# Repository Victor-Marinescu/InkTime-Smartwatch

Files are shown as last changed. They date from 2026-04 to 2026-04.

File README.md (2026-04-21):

# InkTime Smartwatch Project

**InkTime** este un smartwatch conceptual bazat pe microcontrolerul **nRF52840**, proiectat pentru autonomie ridicată prin utilizarea unui ecran E-Paper și optimizarea consumului de energie.

---

## 1. Diagramă Bloc
Sistemul este organizat în jurul MCU-ului nRF52840, care gestionează comunicația cu senzorii via I2C și controlul ecranului via SPI.

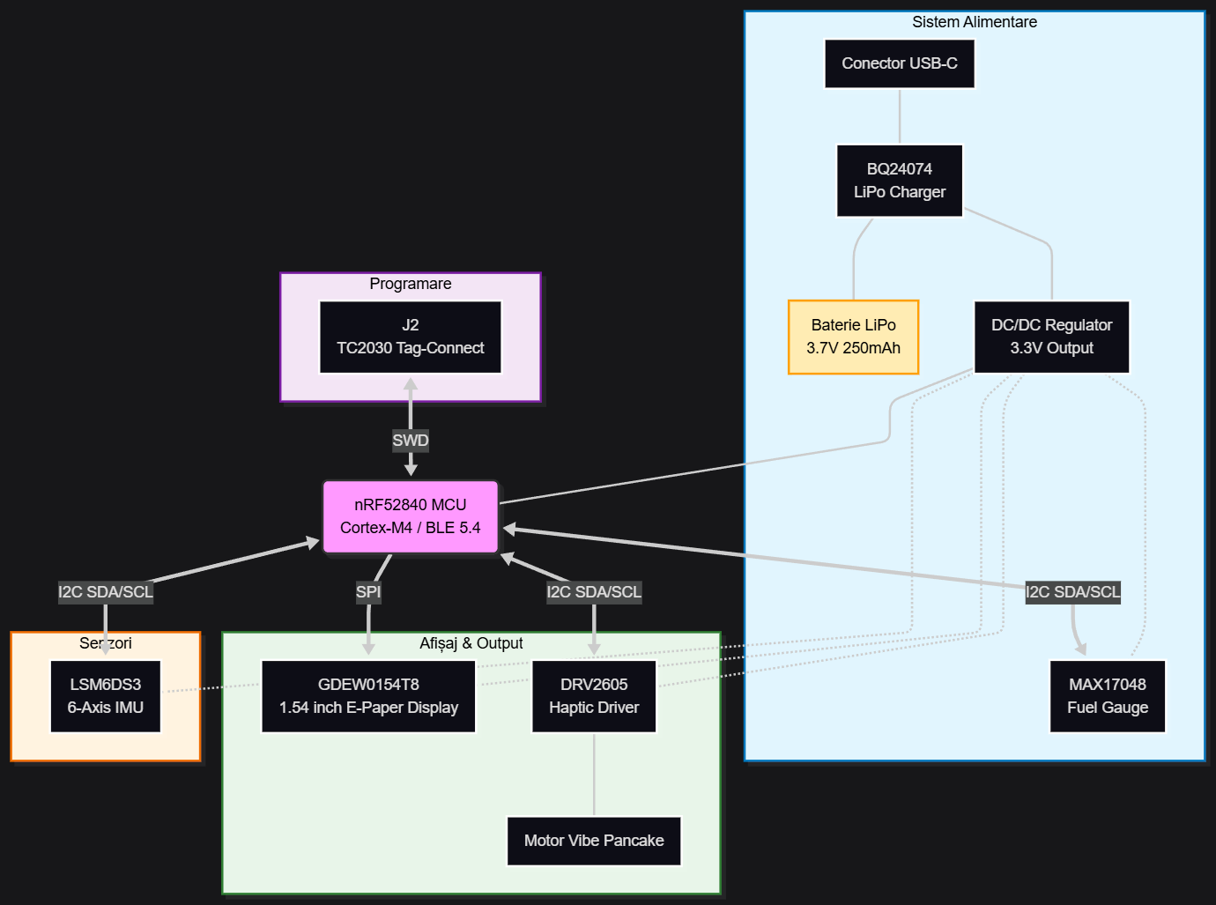
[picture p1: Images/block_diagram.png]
Diagrama Bloc a Sistemului


## 2. Bill Of Materials (BOM)

| Componentă | Descriere | Datasheet |
| :--- | :--- | :--- |
| **nRF52840** | MCU Bluetooth 5.4, ARM Cortex-M4 | [Link](https://jlcpcb.com/partdetail/NordicSemicon-NRF52840_QFAA_FR7/C3606653) |
| **5034802400** | 1.54" E-Paper Display (SPI) | [Link](https://jlcpcb.com/partdetail/MOLEX-5034802400/C122434) |
| **MAX17048** | Fuel Gauge (Monitorizare Baterie) | [Link](https://jlcpcb.com/partdetail/2777647-MAX17048GT10/C2682616) |
| **DRV2605** | Haptic Driver (LRA/ERM) | [Link](https://jlcpcb.com/partdetail/TexasInstruments-DRV2605YZFR/C81079) |
| **LSM6DS3** | IMU (Accelerometru & Giroscop) | [Link](https://jlcpcb.com/partdetail/STMicroelectronics-LSM6DS3TR/C95230) |
| **BQ25180** | IC Management Încărcare Baterie | [Link](https://jlcpcb.com/partdetail/TexasInstruments-BQ25180YBGR/C3682423) |
| **RT6160** | Regulator Buck-Boost 3.3V 2.4A | [Link](https://jlcpcb.com/partdetail/RichtekTech-RT6160AWSC/C7065276) |

---

## 3. Descriere Funcționalitate Hardware

### Module și Senzori
* **Microcontroler (MCU):** nRF52840 (AQFN-73) coordonează procesele BLE și perifericele. Decuplare locală via C14 (4.7 µF), C7/C8/C12 (100 nF).
* **Afișaj E-Paper:** Conectat prin **SPI**. Include pompă de tensiune cu L5 (68 µH) și switch de alimentare Q1/Q3 pentru consum zero în sleep.
* **Haptic Feedback:** Driver DRV2605 (I2C: 0x5A) capabil să ruleze peste 123 de efecte tactile din librăria ROM.
* **Power Management:** * **BQ25180:** Încărcător inteligent (I2C: 0x6A) cu Power Path.
    * **MAX17048:** Monitorizare SOC (I2C: 0x36) via algoritm ModelGauge.
    * **RT6160:** Buck-Boost pentru prag stabil de 3.3V chiar și la descărcarea bateriei sub 3.3V.

---

## 4. Configurație Detaliată Pini (nRF52840)

Am extras configurația completă a pinilor conform mapării hardware finale:

| Pin MCU | AQFN-73 | Funcție | Destinație Hardware | Note Tehnice |
| :--- | :--- | :--- | :--- | :--- |
| **P0.02** | A12 | **SCK** | J1 pin 14 (EPD) | Clock SPI Afișaj |
| **P0.03** | B13 | **MOSI** | J1 pin 15 (EPD) | Date SPI Afișaj |
| **P0.05** | A14 | **CS** | J1 pin 13 (EPD) | Chip Select (Activ LOW) |
| **P0.06** | B15 | **SDA** | I2C Bus Shared | Date senzori (R18 pull-up 3.3k) |
| **P0.07** | A16 | **SCL** | I2C Bus Shared | Clock senzori (R17 pull-up 3.3k) |
| **P0.15** | B19 | **EPD_DC** | J1 pin 11 (EPD) | Data/Command Select |
| **P0.16** | A20 | **EPD_RST**| J1 pin 10 (EPD) | Reset Hardware Afișaj |
| **P0.17** | B21 | **BUSY** | J1 pin 9 (EPD) | Monitorizare stare afișaj |
| **P1.01** | AD22 | **EPD_EN** | Q1 PMOS Gate | Control Power-Cut ecran |
| **P0.13** | AD16 | **SW_UP** | Buton UP | Intrare Digitală (R14 pull-up 10k) |
| **P0.12** | AC17 | **SW_ENT**| Buton ENTER | Intrare Digitală (R15 pull-up 10k) |
| **P0.11** | AD18 | **SW_DN** | Buton DOWN | Intrare Digitală (R16 pull-up 10k) |
| **ANT** | H23 | **RF** | Antenă Ceratent | Adaptare 50 Ω (L1, C3, C4) |
| **SWDIO** | AC24 | **DIO** | J2 pin 2 (Debug) | Programare Serial Wire Data |
| **SWDCLK**| AA24 | **CLK** | J2 pin 4 (Debug) | Programare Serial Wire Clock |

---

## 5. Strategie Design și Review

### Detalii PCB (4 Layere)
* **Lățime Trasee Putere:** 0.3 mm pentru rețelele `VBUS`, `VBAT`, `VREG` și `3V3`.
* **Trasee Date:** 0.15 mm pentru I2C, SPI și semnalele de control.
* **Stackup:**
    * **Layer 1 (Top):** Componente, RF (Antenă) și semnale critice.
    * **Layer 2:** Plan dedicat de alimentare (3.3V / VREG).
    * **Layer 63 (Mid):** Trasee secundare de date.
    * **Layer 64 (Bottom):** Plan de masă (GND) continuu sub zona RF.

### Estimare Consum Energetic
* **MCU (Sleep + RTC + BLE Adv 1Hz):** ~200 µA
* **BMA423 (Pedometru Low-Power):** ~130 µA
* **MAX17048 (Activ):** ~23 µA
* **RT6160 Quiescent:** ~30 µA
* **Total Mediu:** **~390 µA**
* **Autonomie:** ~10 zile (baterie 100mAh) / ~25 zile (baterie 250mAh).

---

## 6. Erori DRC Ignorate 

### Overlap (6 erori)
* **Localizare:** Cele 3 butoane laterale (UP, ENT, DN).
* **Justificare:** Suprapunere asumată între pinii mecanici și via-urile de semnal.

### Drill size (11 erori)
* **Localizare:** Pinii înconjurați de alți pini, fara acces la exterior.
* **Justificare:** S-a folosit câte un via pentru a face conexiunea între pini fără a avea erori de tip Copper Clearance.

### Board Outline Clearance (4 erori)
* **Localizare:** Conector USB-C (J4).
* **Justificare:** Cupru extins până în Dimension layer pentru a asigura fixarea structurală a mufei la marginea carcasei.

---
Licensed under the [Apache 2.0](LICENSE).

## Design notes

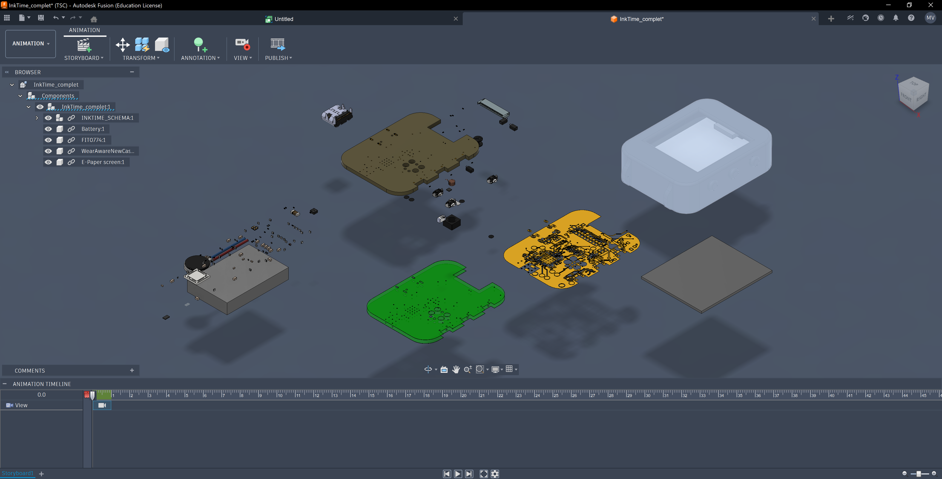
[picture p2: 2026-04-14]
Mechanical/InkTime_explodat.png

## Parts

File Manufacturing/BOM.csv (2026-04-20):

Qty | Value | Device | Package | Parts | Description | ARROW_PART_NUMBER | ARROW_PRICE-STOCK | AVAILABILITY | CHECK_PRICES | COPYRIGHT | DESCRIPTION | DIGI-KEY_PART_NUMBER_1 | DIGI-KEY_PART_NUMBER_2 | DIGI-KEY_PART_NUMBER_3 | HEIGHT | JLCPCB | MANUFACTURER_NAME | MANUFACTURER_PART_NUMBER | MF | MFR_NAME | MOUSER_PART_NUMBER | MOUSER_PRICE-STOCK | MP | PACKAGE | POPULARITY | PRICE | PROD_ID | PURCHASE-URL | SNAPEDA_LINK | TP_SIGNAL_NAME | VALUE
3 | 0 | CPF0201D7K68C1_CPF0201D7K68C1 | CPF0201D7K68C1_0201 | R1, R2, R4 | 7.68k 0201 Thin Film Surface Mount Fixed Resistor +/-0.5% 0.031W CPF0201D7K68C1
1 | 0 | ESP32_C6_LIBRARY_7_JUMPER_SJ | ESP32_C6_LIBRARY_7_JUMPER_SJ | SJ1 | SMD solder JUMPER |  |  |  |  |  |  |  |  |  |  |  |  |  |  |  |  |  |  |  | 3
1 | 0.1uF | GRM011R60J152KE01L_1_GRM011R60J152KE01L | GRM011R60J152KE01L_1_0201 | C42 | Check availability
3 | 0.1uF | NORDIC_NRF_3_CAPACITOR_0201_L | NORDIC_NRF_3_RESC0201_L | C23, C27, C34 | Generic chip capacitor
1 | 0.1uF/50V | NORDIC_NRF_3_CAPACITOR_0201_L | NORDIC_NRF_3_RESC0201_L | EPD_C5 | Generic chip capacitor
1 | 0.47 | CPF0201D7K68C1_CPF0201D7K68C1 | CPF0201D7K68C1_0201 | R1_EP_DR | 7.68k 0201 Thin Film Surface Mount Fixed Resistor +/-0.5% 0.031W CPF0201D7K68C1
5 | 100nF | NORDIC_NRF_3_CAPACITOR_0201_L | NORDIC_NRF_3_RESC0201_L | C5, C7, C8, C12, C19 | Generic chip capacitor
1 | 100pF | NORDIC_NRF_3_CAPACITOR_0201_L | NORDIC_NRF_3_RESC0201_L | C11 | Generic chip capacitor
6 | 10K | CPF0201D7K68C1_CPF0201D7K68C1 | CPF0201D7K68C1_0201 | R2_EP_DR, R5, R7, R8, R9, R_PWR_EPD | 7.68k 0201 Thin Film Surface Mount Fixed Resistor +/-0.5% 0.031W CPF0201D7K68C1
1 | 10uF | NORDIC_NRF_3_CAPACITOR_0402_L | NORDIC_NRF_3_RESC0402_L | C1-EP-DR | Generic chip capacitor
1 | 10uF | NORDIC_NRF_3_CAPACITOR_0402_N | NORDIC_NRF_3_RESC0402_N | C24 | Generic chip capacitor
1 | 10uF | PERFECT_0402_CAP_0402 | PERFECT_0402_0402 | C39 | 0402 (1005 Metric)
1 | 10uH | NORDIC_NRF_2_INDUCTOR_0201_L | NORDIC_NRF_2_RESC0201_L | L2 | Generic chip inductor
4 | 12pF | NORDIC_NRF_3_CAPACITOR_0201_L | NORDIC_NRF_3_RESC0201_L | C17, C18, XC1, XC2 | Generic chip capacitor
1 | 15nH | NORDIC_NRF_2_INDUCTOR_0201_L | NORDIC_NRF_2_RESC0201_L | L3 | Generic chip inductor
2 | 1pF | NORDIC_NRF_3_CAPACITOR_0201_L | NORDIC_NRF_3_RESC0201_L | C3, C4 | Generic chip capacitor
5 | 1uF | NORDIC_NRF_3_CAPACITOR_0402_L | NORDIC_NRF_3_RESC0402_L | C15, C29, C30, C31, C32 | Generic chip capacitor
2 | 1uF | NORDIC_NRF_3_CAPACITOR_0402_N | NORDIC_NRF_3_RESC0402_N | C37, C38 | Generic chip capacitor
9 | 1uF/50V | NORDIC_NRF_3_CAPACITOR_0402_L | NORDIC_NRF_3_RESC0402_L | EPD_C1, EPD_C2, EPD_C6, EPD_C7, EPD_C8, EPD_C9, EPD_C10, EPD_C11, EPD_C12 | Generic chip capacitor
1 | 2.2 | CPF0201D7K68C1_CPF0201D7K68C1 | CPF0201D7K68C1_0201 | R_TYPE_SEL | 7.68k 0201 Thin Film Surface Mount Fixed Resistor +/-0.5% 0.031W CPF0201D7K68C1
3 | 2025-10-22_07-23-44_LIBRARY_EVP-AKE31ASW_EVP-AKE31A_PAN | 2025-10-22_07-23-44_LIBRARY_EVP-AKE31ASW_EVP-AKE31A_PAN | 2025-10-22_07-23-44_LIBRARY_SW_EVP-AKE31A_PAN | SW_DN, SW_ENT, SW_UP |  |  |  |  |  | Copyright (C) 2025 Ultra Librarian. All rights reserved. |  | P123437TR-ND | P123437CT-ND | P123437DKR-ND |  |  | Panasonic | EVP-AKE31A
1 | 20V/4.2A/52mO/1.4W | ESP32_C6_LIBRARY_4_ESP32_WROVER_SPARKFUN-DISCRETESEMI_MOSFET_PCH-DMG2305UX-7 | ESP32_C6_LIBRARY_4_ESP32_C6_LIBRARY_4_ESP32_C6_LIBRARY_4_ESP32_C6_LIBRARY_4_ESP32_WROVER_SPARKFUN-DISCRETESEMI_SOT23-3 | DMG2305UX-7 | P-channel MOSFETs |  |  |  |  |  |  |  |  |  |  |  |  |  |  |  |  |  |  |  |  |  | TRAN-14388 |  |  |  | 20V/4.2A/52mO/1.4W
2 | 22uF | NORDIC_NRF_3_CAPACITOR_0402_N | NORDIC_NRF_3_RESC0402_N | C25, C33 | Generic chip capacitor
1 | 2450AT18B100E | 2450AT18B100E_2450AT18B100E | 2450AT18B100E_ANTC3216X140N | ANT1 | Antennas 2.45GHz ANTENNA | 2450AT18B100E | https://www.arrow.com/en/products/2450at18b100e/johanson-dielectrics?utm_currency=USD&region=nac |  |  |  | Antennas 2.45GHz ANTENNA |  |  |  | 1.4mm |  | JOHANSON TECHNOLOGY | 2450AT18B100E |  |  | 609-2450AT18B100E | https://www.mouser.co.uk/ProductDetail/Johanson-Technology/2450AT18B100E?qs=yCnrNFeXz%252Bh5MFsFIXGZGA%3D%3D
1 | 3.9nH | NORDIC_NRF_2_INDUCTOR_0201_L | NORDIC_NRF_2_RESC0201_L | L1 | Generic chip inductor
1 | 32.768kHz | NORDIC_NRF_1_XTAL_32KHZ | NORDIC_NRF_1_XTAL_3215_N | X2
1 | 32MHz | NORDIC_NRF_XTAL_32MHZ | NORDIC_NRF_BT-XTAL_2016_N | X1
2 | 3K3 | CPF0201D7K68C1_CPF0201D7K68C1 | CPF0201D7K68C1_0201 | R17, R18 | 7.68k 0201 Thin Film Surface Mount Fixed Resistor +/-0.5% 0.031W CPF0201D7K68C1
1 | 4.7uF | NORDIC_NRF_3_CAPACITOR_0603_N | NORDIC_NRF_3_RESC0603_N | C43 | Generic chip capacitor
4 | 4.7uF | PERFECT_0402_CAP_0402 | PERFECT_0402_0402 | C6, C14, C20, C21 | 0402 (1005 Metric)
1 | 4.7uF/25V | NORDIC_NRF_3_CAPACITOR_0402_L | NORDIC_NRF_3_RESC0402_L | C2-EP-DR | Generic chip capacitor
1 | 47nF | PERFECT_0402_CAP_0402 | PERFECT_0402_0402 | C16 | 0402 (1005 Metric)
1 | 503480-2400 | 503480-2400_503480-2400 | 503480-2400_5034802400 | J1 | FFC & FPC Connectors 0.5mm FPC RA SMT Dual Contact 24Ckt |  |  |  |  |  | FFC & FPC Connectors 0.5mm FPC RA SMT Dual Contact 24Ckt |  |  |  | 1.87mm |  | Molex | 503480-2400 |  |  | 538-503480-2400 | https://www.mouser.co.uk/ProductDetail/Molex/503480-2400?qs=OAhjpuo3Vu7efIoxFh9AOw%3D%3D
2 | 5K1 | CPF0201D7K68C1_CPF0201D7K68C1 | CPF0201D7K68C1_0201 | R1_USB, R2_USB | 7.68k 0201 Thin Film Surface Mount Fixed Resistor +/-0.5% 0.031W CPF0201D7K68C1
1 | 68uH | ESP32_C6_LIBRARY_2_744043680IND_4828-WE-TPC_WRE | ESP32_C6_LIBRARY_2_IND_4828-WE-TPC_WRE | L5 |  |  |  |  |  | Copyright (C) 2024 Ultra Librarian. All rights reserved. |  |  |  |  |  |  |  | 744043680 |  | Wurth Electronics
1 | 820pF | NORDIC_NRF_3_CAPACITOR_0201_L | NORDIC_NRF_3_RESC0201_L | C9 | Generic chip capacitor
1 | BMA423 | BMA423_BMA423 | BMA423_BMA423 | IC3 | Accelerometers Triaxial low-g 12bit Acceleration Sensor | BMA423 | https://www.arrow.com/en/products/bma423/bosch |  |  |  | Accelerometers Triaxial low-g 12bit Acceleration Sensor |  |  |  | 1mm |  | BOSCH | BMA423 |  |  | 262-BMA423 | https://www.mouser.co.uk/ProductDetail/Bosch-Sensortec/BMA423?qs=HXFqYaX1Q2xC%252BSgeGoX3mg%3D%3D
1 | BQ25180YBGR | BQ25180YBGR_BQ25180YBGR | BQ25180YBGR_BGA8C40P2X4_100X155X50 | IC1 | Charger IC Lithium Ion/Polymer, Lithium Iron Phosphate 8-DSBGA (1.6x1.1) | BQ25180YBGR | https://www.arrow.com/en/products/bq25180ybgr/texas-instruments?utm_currency=USD&region=nac |  |  |  | Charger IC Lithium Ion/Polymer | Lithium Iron Phosphate 8-DSBGA (1.6x1.1) |  |  |  | 0.5mm |  | Texas Instruments | BQ25180YBGR |  |  | 595-BQ25180YBGR | https://www.mouser.co.uk/ProductDetail/Texas-Instruments/BQ25180YBGR?qs=doiCPypUmgEWjAK%252BJAX6Tw%3D%3D
1 | DRV2605YZFR | DRV2605YZFR_DRV2605YZFR | DRV2605YZFR_BGA9C50P3X3_144X144X62 | IC4 | Haptic Driver for ERM/LRA with Built-In Library and Smart Loop Architecture | DRV2605YZFR | https://www.arrow.com/en/products/drv2605yzfr/texas-instruments?region=nac |  |  |  | Haptic Driver for ERM/LRA with Built-In Library and Smart Loop Architecture |  |  |  | 0.625mm |  | Texas Instruments | DRV2605YZFR
1 | FTC252012SR47MBCA | MLP2016SR47MT0S1_FTC252012SR47MBCA | MLP2016SR47MT0S1_INDC2016X100N | L7 | SMD / SMT Inductors (Coils), L=0.47?H, L x W x T : |  |  |  |  |  | SMD / SMT Inductors (Coils) | L=0.47?H | L x W x T : |  |  |  | 1mm | https://jlcpcb.com/partdetail/6763488-FTC252012SR47MBCA/C5832368 | TDK | FTC252012SR47MBCA
12 | HECTOR_WATCH_1_TPTP20R | HECTOR_WATCH_1_TPTP20R | HECTOR_WATCH_1_TP20R | TP_3.3V, TP_3V3, TP_BAT_GND, TP_GND, TP_RESET, TP_SCL, TP_SDA, TP_SWDCLK, TP_SWDIO, TP_SWO, TP_VBAT, TP_VREG | Test pad |  |  |  |  |  |  |  |  |  |  |  |  |  |  |  |  |  |  |  | 2
1 | KH-TYPE-C-16P | KH-TYPE-C-16P_KH-TYPE-C-16P | KH-TYPE-C-16P_KINGHELM_KH-TYPE-C-16P | J4 | Check availability |  |  | Not in stock | https://www.snapeda.com/parts/KH-TYPE-C-16P/Kinghelm/view-part/?ref=eda |  |  |  |  |  |  |  |  |  | kinghelm |  |  |  | KH-TYPE-C-16P | None |  | None |  |  | https://www.snapeda.com/parts/KH-TYPE-C-16P/Kinghelm/view-part/?ref=snap
1 | MAX17048G+T10 | ESP32_C6_LIBRARY_MAX17048G+T10 | ESP32_C6_LIBRARY_SON50P200X200X80-9N | U3 | Check availability |  |  | In Stock | https://www.snapeda.com/parts/MAX17048G+T10/Analog+Devices/view-part/?ref=eda |  | 3µA 1-Cell/2-Cell Fuel Gauge with ModelGauge |  |  |  |  |  |  |  | Analog Devices |  |  |  | MAX17048G+T10 | TDFN-8 Maxim |  | None |  | https://www.snapeda.com/api/url_track_click_mouser/?unipart_id=329239&manufacturer=Analog Devices&part_name=MAX17048G+T10&search_term=None | https://www.snapeda.com/parts/MAX17048G+T10/Analog+Devices/view-part/?ref=snap
3 | MBR0530 | ESP32_C6_LIBRARY_5_MBR0530 | ESP32_C6_LIBRARY_5_SOD3716X135N | D2, D4, D5 | ON SEMICONDUCTOR - MBR0530 - DIODE, SCHOTTKY, 0.5A, 30V, SOD-123 |  |  | In Stock | https://www.snapeda.com/parts/MBR0530/Onsemi/view-part/?ref=eda |  | Diode Schottky 30 V 500mA Surface Mount SOD-123 |  |  |  |  |  |  |  | ON Semiconductor |  |  |  | MBR0530 | SOD-123-2 ON Semiconductor |  | None |  | https://www.snapeda.com/api/url_track_click_mouser/?unipart_id=179458&manufacturer=ON Semiconductor&part_name=MBR0530&search_term=None | https://www.snapeda.com/parts/MBR0530/Onsemi/view-part/?ref=snap
3 | N.C. | NORDIC_NRF_3_CAPACITOR_0201_L | NORDIC_NRF_3_RESC0201_L | C10, C13, C22 | Generic chip capacitor
1 | NRF52840_QF | NORDIC_NRF_4_NRF52840_QF | NORDIC_NRF_4_AQFN50P700X700X85_HS-74N | U1 | nRF52840
1 | RT6160AWSC | RT6160AWSC_RT6160AWSC | RT6160AWSC_BGA15C40P3X5_140X230X60 | IC2 | Buck-Boost Regulator Positive Output Step-Up/Step-Down I2C DC-DC Controller IC 15-WL-CSP (BSC) (1.4x2.3) |  |  |  |  |  | Buck-Boost Regulator Positive Output Step-Up/Step-Down I2C DC-DC Controller IC 15-WL-CSP (BSC) (1.4x2.3) |  |  |  | 0.6mm |  | RICHTEK | RT6160AWSC |  |  | 835-RT6160AWSC | https://www.mouser.co.uk/ProductDetail/Richtek/RT6160AWSC?qs=amGC7iS6iy%2FLd9PSoixZXQ%3D%3D
1 | SI1308EDL-T1-GE3 | ESP32_C6_LIBRARY_6_SI1308EDL-T1-GE3 | ESP32_C6_LIBRARY_6_SOT65P210X110-3N | Q1 | MOSFET N-Ch 30V 1.5A TrenchFET SC70 Vishay Si1308EDL-T1-GE3 N-channel MOSFET Transistor, 1.5 A, 30 V, 3-Pin SC-70 |  |  | In Stock | https://www.snapeda.com/parts/SI1308EDL-T1-GE3/Vishay+Siliconix/view-part/?ref=eda |  | Si1308EDL-T1-GE3 N-channel MOSFET Transistor | 1.5 A | 30 V | 3-Pin SC-70 | Siliconix / Vishay SI1308EDL-T1-GE3 |  |  |  |  |  |  |  | Vishay Siliconix |  |  |  | SI1308EDL-T1-GE3 | SOT-323 Vishay Semiconductor |  | None |  | https://www.snapeda.com/api/url_track_click_mouser/?unipart_id=274603&manufacturer=Vishay Siliconix&part_name=SI1308EDL-T1-GE3&search_term=None
1 | TC2030-IDC | TC2030-IDC_TC2030-IDC | TC2030-IDC_TC2030IDC | J2 | CABLE ADAPTER 6 POS |  |  |  |  |  | CABLE ADAPTER 6 POS |  |  |  | 19mm |  | Tag Connect | TC2030-IDC
1 | USBLC6-2SC6Y | ESP32_C6_LIBRARY_3_USBLC6-2SC6Y | ESP32_C6_LIBRARY_3_SOT95P280X145-6N | D3 | Low Cap. ESD Protection Auto SOT-23-6 STMicroelectronics USBLC6-2SC6Y, Dual Uni-Directional TVS Diode Array, 6-Pin SOT-23 |  |  | In Stock | https://www.snapeda.com/parts/USBLC6-2SC6Y/STMicroelectronics/view-part/?ref=eda |  | 17V Clamp 5A (8/20µs) Ipp Tvs Diode Surface Mount SOT-23-6 |  |  |  |  |  |  |  | STMicroelectronics |  |  |  | USBLC6-2SC6Y | SOT-23-6 STMicroelectronics |  | None |  |  | https://www.snapeda.com/parts/USBLC6-2SC6Y/STMicroelectronics/view-part/?ref=snap

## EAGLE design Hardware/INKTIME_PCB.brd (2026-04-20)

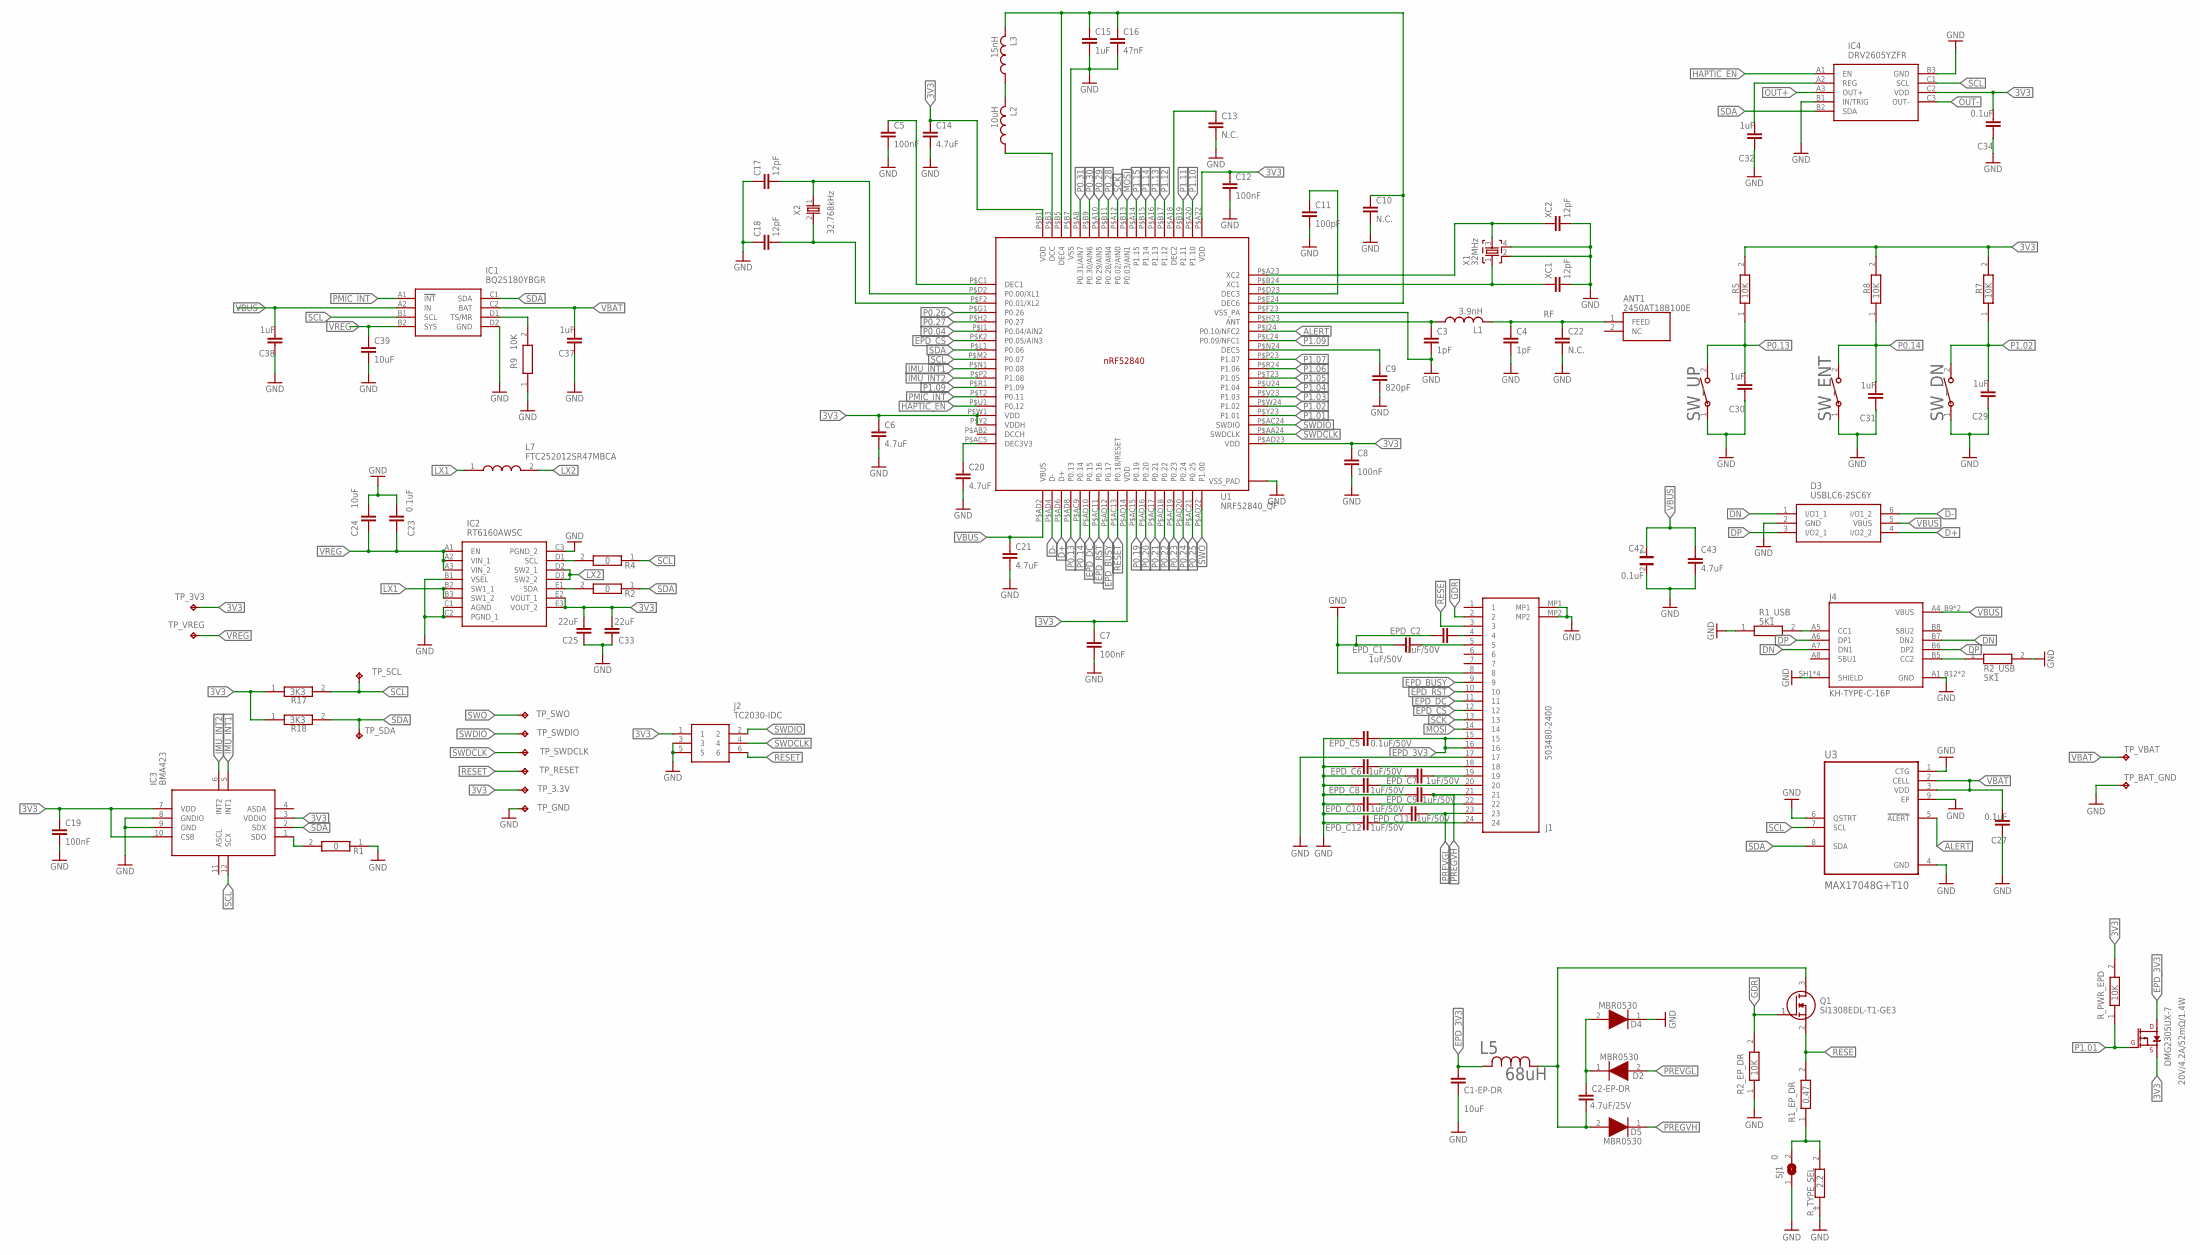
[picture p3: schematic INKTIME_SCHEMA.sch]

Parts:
ANT1: 2450AT18B100E; 2450AT18B100E_ANTC3216X140N
C1-EP-DR: 10uF; NORDIC_NRF_3_RESC0402_L
C2-EP-DR: 4.7uF/25V; NORDIC_NRF_3_RESC0402_L
C3, C4: 1pF; NORDIC_NRF_3_RESC0201_L
C5, C7, C8, C12, C19: 100nF; NORDIC_NRF_3_RESC0201_L
C6, C14, C20, C21: 4.7uF; PERFECT_0402_0402
C9: 820pF; NORDIC_NRF_3_RESC0201_L
C10, C13, C22: N.C.; NORDIC_NRF_3_RESC0201_L
C11: 100pF; NORDIC_NRF_3_RESC0201_L
C15, C29, C30, C31, C32: 1uF; NORDIC_NRF_3_RESC0402_L
C16: 47nF; PERFECT_0402_0402
C17, C18: 12pF; NORDIC_NRF_3_RESC0201_L
C23, C27, C34: 0.1uF; NORDIC_NRF_3_RESC0201_L
C24: 10uF; NORDIC_NRF_3_RESC0402_N
C25, C33: 22uF; NORDIC_NRF_3_RESC0402_N
C37, C38: 1uF; NORDIC_NRF_3_RESC0402_N
C39: 10uF; PERFECT_0402_0402
C42: 0.1uF; GRM011R60J152KE01L_1_0201
C43: 4.7uF; NORDIC_NRF_3_RESC0603_N
D2, D4, D5: MBR0530; ESP32_C6_LIBRARY_5_SOD3716X135N
D3: USBLC6-2SC6Y; ESP32_C6_LIBRARY_3_SOT95P280X145-6N
DMG2305UX-7: 20V/4.2A/52mΩ/1.4W; ESP32_C6_LIBRARY_4_ESP32_C6_LIBRARY_4_ESP32_C6_LIBRARY_4_ES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
EPD_C1, EPD_C2, EPD_C6, EPD_C7, EPD_C8, EPD_C9, EPD_C10, EPD_C11, EPD_C12: 1uF/50V; NORDIC_NRF_3_RESC0402_L
EPD_C5: 0.1uF/50V; NORDIC_NRF_3_RESC0201_L
IC1: BQ25180YBGR; BQ25180YBGR_BGA8C40P2X4_100X155X50
IC2: RT6160AWSC; RT6160AWSC_BGA15C40P3X5_140X230X60
IC3: BMA423; BMA423_BMA423
IC4: DRV2605YZFR; DRV2605YZFR_BGA9C50P3X3_144X144X62
J1: 503480-2400; 503480-2400_5034802400
J2: TC2030-IDC; TC2030-IDC_TC2030IDC
J4: KH-TYPE-C-16P; KH-TYPE-C-16P_KINGHELM_KH-TYPE-C-16P
L1: 3.9nH; NORDIC_NRF_2_RESC0201_L
L2: 10uH; NORDIC_NRF_2_RESC0201_L
L3: 15nH; NORDIC_NRF_2_RESC0201_L
L5: 68uH; ESP32_C6_LIBRARY_2_IND_4828-WE-TPC_WRE
L7: FTC252012SR47MBCA; MLP2016SR47MT0S1_INDC2016X100N
Q1: SI1308EDL-T1-GE3; ESP32_C6_LIBRARY_6_SOT65P210X110-3N
R1, R2, R4: 0; CPF0201D7K68C1_0201
R1_EP_DR: 0.47; CPF0201D7K68C1_0201
R1_USB, R2_USB: 5K1; CPF0201D7K68C1_0201
R2_EP_DR, R5, R7, R8, R9: 10K; CPF0201D7K68C1_0201
R17, R18: 3K3; CPF0201D7K68C1_0201
R_PWR_EPD: 10K; CPF0201D7K68C1_0201
R_TYPE_SEL: 2.2; CPF0201D7K68C1_0201
SJ1: 0; ESP32_C6_LIBRARY_7_JUMPER_SJ
SW_DN: 2025-10-22_07-23-44_LIBRARY_EVP-AKE31ASW_EVP-AKE3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; 2025-10-22_07-23-44_LIBRARY_SW_EVP-AKE31A_PAN
SW_ENT: 2025-10-22_07-23-44_LIBRARY_EVP-AKE31ASW_EVP-AKE3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; 2025-10-22_07-23-44_LIBRARY_SW_EVP-AKE31A_PAN
SW_UP: 2025-10-22_07-23-44_LIBRARY_EVP-AKE31ASW_EVP-AKE3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; 2025-10-22_07-23-44_LIBRARY_SW_EVP-AKE31A_PAN
TP_3.3V, TP_3V3: HECTOR_WATCH_1_TPTP20R; HECTOR_WATCH_1_TP20R
TP_BAT_GND: HECTOR_WATCH_1_TPTP20R; HECTOR_WATCH_1_TP20R
TP_GND: HECTOR_WATCH_1_TPTP20R; HECTOR_WATCH_1_TP20R
TP_RESET: HECTOR_WATCH_1_TPTP20R; HECTOR_WATCH_1_TP20R
TP_SCL: HECTOR_WATCH_1_TPTP20R; HECTOR_WATCH_1_TP20R
TP_SDA: HECTOR_WATCH_1_TPTP20R; HECTOR_WATCH_1_TP20R
TP_SWDCLK: HECTOR_WATCH_1_TPTP20R; HECTOR_WATCH_1_TP20R
TP_SWDIO: HECTOR_WATCH_1_TPTP20R; HECTOR_WATCH_1_TP20R
TP_SWO: HECTOR_WATCH_1_TPTP20R; HECTOR_WATCH_1_TP20R
TP_VBAT: HECTOR_WATCH_1_TPTP20R; HECTOR_WATCH_1_TP20R
TP_VREG: HECTOR_WATCH_1_TPTP20R; HECTOR_WATCH_1_TP20R
U1: NRF52840_QF; NORDIC_NRF_4_AQFN50P700X700X85_HS-74N
U3: MAX17048G+T10; ESP32_C6_LIBRARY_SON50P200X200X80-9N
X1: 32MHz; NORDIC_NRF_BT-XTAL_2016_N
X2: 32.768kHz; NORDIC_NRF_1_XTAL_3215_N
XC1, XC2: 12pF; NORDIC_NRF_3_RESC0201_L

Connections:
3V3: C6.1, C7.1, C8.1, C12.1, C14.1, C19.1, C25.1, C33.1, C34.2, DMG2305UX-7.2 (S), IC2.E2 (VOUT_1), IC2.E3 (VOUT_2), IC3.3 (VDDIO), IC3.7 (VDD), IC3.10 (CSB), IC4.C2 (VDD), J2.1, R5.2, R7.2, R8.2, R17.1, R18.1, R_PWR_EPD.2, TP_3.3V.TP, TP_3V3.TP, U1.P$A22 (VDD), U1.P$AD14 (VDD), U1.P$AD23 (VDD), U1.P$B1 (VDD), U1.P$W1 (VDD), U1.P$Y2 (VDDH)
ALERT: U1.P$J24 (P0.10/NFC2), U3.5 (!ALERT)
D+: D3.4 (I/O2_2), U1.P$AD6 (D+)
D-: D3.6 (I/O1_2), U1.P$AD4 (D-)
DN: D3.1 (I/O1_1), J4.A7 (DN1), J4.B7 (DN2)
DP: D3.3 (I/O2_1), J4.A6 (DP1), J4.B6 (DP2)
EPD_3V3: C1-EP-DR.2, DMG2305UX-7.3 (D), EPD_C5.2, J1.15, J1.16, L5.2
EPD_BUSY: J1.9, U1.P$AD12 (P0.17)
EPD_CS: J1.12, U1.P$K2 (P0.05/AIN3)
EPD_DC: J1.11, U1.P$AD10 (P0.15)
EPD_RST: J1.10, U1.P$AC11 (P0.16)
GDR: J1.2, Q1.1 (G), R2_EP_DR.2
GND: C1-EP-DR.1, C3.2, C4.2, C5.2, C6.2, C7.2, C8.2, C9.2, C10.2, C11.2, C12.2, C13.2, C14.2, C15.2, C16.2, C17.1, C18.1, C19.2, C20.2, C21.2, C22.2, C23.1, C24.1, C25.2, C27.1, C29.1, C30.1, C31.1, C32.1, C33.2, C34.1, C37.1, C38.1, C39.2, C42.2, C43.2, D3.2 (GND), D4.1 (K), EPD_C1.1, EPD_C2.1, EPD_C5.1, EPD_C6.1, EPD_C7.1, EPD_C8.1, EPD_C9.1, EPD_C10.1, EPD_C11.1, EPD_C12.1, IC1.D2 (GND), IC2.B1 (VSEL), IC2.C1 (AGND), IC2.C2 (PGND_1), IC2.C3 (PGND_2), IC3.8 (GNDIO), IC3.9 (GND), IC4.B1 (IN/TRIG), IC4.B3 (GND), J1.8, J1.17, J1.MP1, J1.MP2, J2.3, J2.5, J4.A1_B12 (GND), J4.A12_B1 (GND), J4.SH1 (SHIELD), J4.SH2 (SHIELD), J4.SH3 (SHIELD), J4.SH4 (SHIELD), R1.1, R1_USB.1, R2_EP_DR.1, R2_USB.2, R9.1, R_TYPE_SEL.1, SJ1.1, SW_DN.1, SW_ENT.1, SW_UP.1, TP_BAT_GND.TP, TP_GND.TP, U1.P$74 (VSS_PAD), U1.P$75 (VSS_PAD), U1.P$76 (VSS_PAD), U1.P$77 (VSS_PAD), U1.P$78 (VSS_PAD), U1.P$79 (VSS_PAD), U1.P$80 (VSS_PAD), U1.P$81 (VSS_PAD), U1.P$82 (VSS_PAD), U1.P$83 (VSS_PAD), U1.P$84 (VSS_PAD), U1.P$85 (VSS_PAD), U1.P$86 (VSS_PAD), U1.P$87 (VSS_PAD), U1.P$88 (VSS_PAD), U1.P$89 (VSS_PAD), U1.P$90 (VSS_PAD), U1.P$B7 (VSS), U1.P$F23 (VSS_PA), U3.1 (CTG), U3.4 (GND), U3.6 (QSTRT), U3.9 (EP), X1.2, X1.4, XC1.2, XC2.2
HAPTIC_EN: IC4.A1 (EN), U1.P$U1 (P0.12)
IMU_INT1: IC3.5 (INT1), U1.P$N1 (P0.08)
IMU_INT2: IC3.6 (INT2), U1.P$P2 (P1.08)
LX1: IC2.B2 (SW1_1), IC2.B3 (SW1_2), L7.1
LX2: IC2.D2 (SW2_1), IC2.D3 (SW2_2), L7.2
MOSI: J1.14, U1.P$B13 (P0.03/AIN1)
unnamed: IC2.D1 (SCL), R4.2
unnamed: IC1.D1 (TS/MR), R9.2
unnamed: IC2.E1 (SDA), R2.2
unnamed: U1.P$B24 (XC1), X1.1, XC1.1
unnamed: U1.P$A23 (XC2), X1.3, XC2.1
unnamed: C10.1, C15.1, C16.1, L3.2, U1.P$B5 (DEC4), U1.P$E24 (DEC6)
unnamed: IC3.1 (SDO), R1.2
unnamed: L2.2, L3.1
unnamed: C13.1, U1.P$A18 (DEC2)
unnamed: L2.1, U1.P$B3 (DCC)
unnamed: C32.2, IC4.A2 (REG)
unnamed: C5.1, U1.P$C1 (DEC1)
unnamed: EPD_C6.2, J1.18
unnamed: C9.1, U1.P$N24 (DEC5)
unnamed: C17.2, U1.P$D2 (P0.00/XL1), X2.1
unnamed: C18.2, U1.P$F2 (P0.01/XL2), X2.2
unnamed: C20.1, U1.P$AC5 (DEC3V3)
unnamed: C3.1, L1.1, U1.P$H23 (ANT)
unnamed: EPD_C12.2, J1.24
unnamed: EPD_C2.2, J1.4
unnamed: C11.1, U1.P$D23 (DEC3)
unnamed: J4.B5 (CC2), R2_USB.1
unnamed: J4.A5 (CC1), R1_USB.2
unnamed: EPD_C1.2, J1.5
unnamed: EPD_C10.2, J1.22
unnamed: EPD_C8.2, J1.20
unnamed: EPD_C7.2, J1.19
unnamed: R1_EP_DR.1, R_TYPE_SEL.2, SJ1.2
unnamed: C2-EP-DR.1, D5.2 (A), L5.1, Q1.3 (D)
unnamed: C2-EP-DR.2, D2.1 (K), D4.2 (A)
OUT+: IC4.A3 (OUT+)
OUT-: IC4.C3 (OUT-)
P0.04: U1.P$J1 (P0.04/AIN2)
P0.13: C30.2, R5.1, SW_UP.2, U1.P$AD8 (P0.13)
P0.14: C31.2, R8.1, SW_ENT.2, U1.P$AC9 (P0.14)
P0.19: U1.P$AC15 (P0.19)
P0.20: U1.P$AD16 (P0.20)
P0.21: U1.P$AC17 (P0.21)
P0.22: U1.P$AD18 (P0.22)
P0.23: U1.P$AC19 (P0.23)
P0.24: U1.P$AD20 (P0.24)
P0.25: U1.P$AC21 (P0.25)
P0.26: U1.P$G1 (P0.26)
P0.27: U1.P$H2 (P0.27)
P0.28: U1.P$B11 (P0.28/AIN4)
P0.29: U1.P$A10 (P0.29/AIN5)
P0.30: U1.P$B9 (P0.30/AIN6)
P0.31: U1.P$A8 (P0.31/AIN7)
P1.01: DMG2305UX-7.1 (G), R_PWR_EPD.1, U1.P$Y23 (P1.01)
P1.02: C29.2, R7.1, SW_DN.2, U1.P$W24 (P1.02)
P1.03: U1.P$V23 (P1.03)
P1.04: U1.P$U24 (P1.04)
P1.05: U1.P$T23 (P1.05)
P1.06: U1.P$R24 (P1.06)
P1.07: U1.P$P23 (P1.07)
P1.09: U1.P$L24 (P0.09/NFC1), U1.P$R1 (P1.09)
P1.10: U1.P$A20 (P1.10)
P1.11: U1.P$B19 (P1.11)
P1.12: U1.P$B17 (P1.12)
P1.13: U1.P$A16 (P1.13)
P1.14: U1.P$B15 (P1.14)
P1.15: U1.P$A14 (P1.15)
PMIC_INT: IC1.A1 (!INT), U1.P$T2 (P0.11)
PREGVH: D5.1 (K), EPD_C9.2, J1.21
PREVGL: D2.2 (A), EPD_C11.2, J1.23
RESE: J1.3, Q1.2 (S), R1_EP_DR.2
RESET: J2.6, TP_RESET.TP, U1.P$AC13 (P0.18/RESET)
RF: ANT1.1 (FEED), C4.1, C22.1, L1.2
SCK: J1.13, U1.P$A12 (P0.02/AIN0)
SCL: IC1.B1 (SCL), IC3.12 (SCX), IC4.C1 (SCL), R4.1, R17.2, TP_SCL.TP, U1.P$M2 (P0.07), U3.7 (SCL)
SDA: IC1.C1 (SDA), IC3.2 (SDX), IC4.B2 (SDA), R2.1, R18.2, TP_SDA.TP, U1.P$L1 (P0.06), U3.8 (SDA)
SWDCLK: J2.4, TP_SWDCLK.TP, U1.P$AA24 (SWDCLK)
SWDIO: J2.2, TP_SWDIO.TP, U1.P$AC24 (SWDIO)
SWO: TP_SWO.TP, U1.P$AD22 (P1.00)
VBAT: C27.2, C37.2, IC1.C2 (BAT), TP_VBAT.TP, U3.2 (CELL), U3.3 (VDD)
VBUS: C21.1, C38.2, C42.1, C43.1, D3.5 (VBUS), IC1.A2 (IN), J4.A4_B9 (VBUS), J4.A9_B4 (VBUS), U1.P$AD2 (VBUS)
VREG: C23.2, C24.2, C39.1, IC1.B2 (SYS), IC2.A1 (EN), IC2.A2 (VIN_1), IC2.A3 (VIN_2), TP_VREG.TP

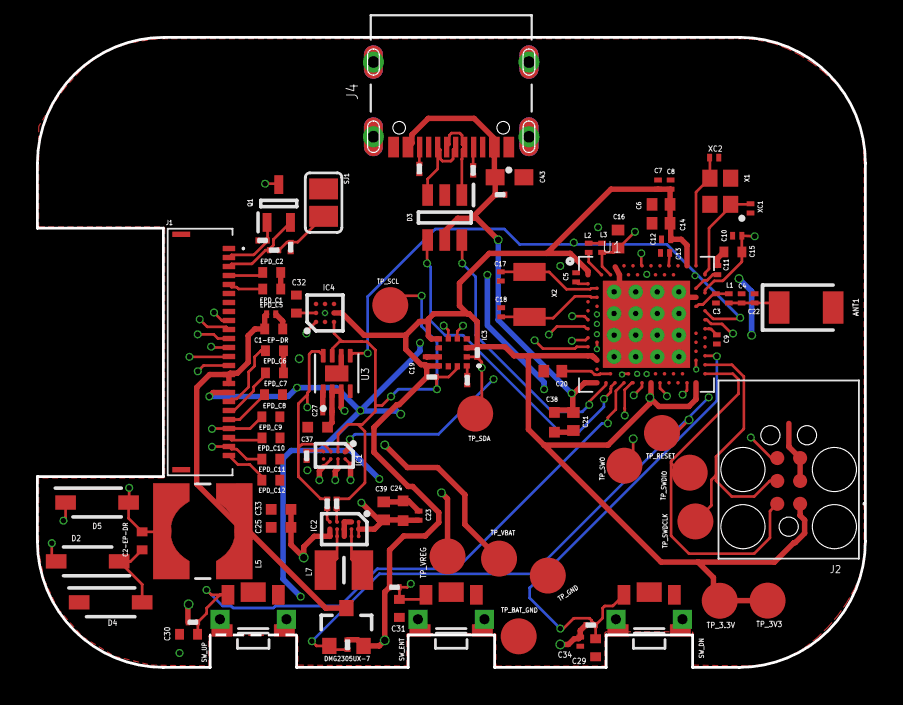
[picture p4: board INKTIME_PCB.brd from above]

Board: 4 copper layers, 46.0 x 35.0 mm, 103 parts (0 on the bottom side), 69 nets.

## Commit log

2026-04-10 Prima versiune: SCH, PCB, 3D si documentatie
    [INKTIME_3D.step, INKTIME_PCB.brd, INKTIME_SCHEMA.sch]
2026-04-11 fix issue 1
    [INKTIME_3D.step, INKTIME_PCB.brd, INKTIME_SCHEMA.sch]
2026-04-20 Fixed all issues, have to replace placeholder in readme
    [INKTIME_PCB.brd, INKTIME_SCHEMA.sch]
2026-04-20 Added Manufacturing files
    [BOM.csv, PnP.csv]

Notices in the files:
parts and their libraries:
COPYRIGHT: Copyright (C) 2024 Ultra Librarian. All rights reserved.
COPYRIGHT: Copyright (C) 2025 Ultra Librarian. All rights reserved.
